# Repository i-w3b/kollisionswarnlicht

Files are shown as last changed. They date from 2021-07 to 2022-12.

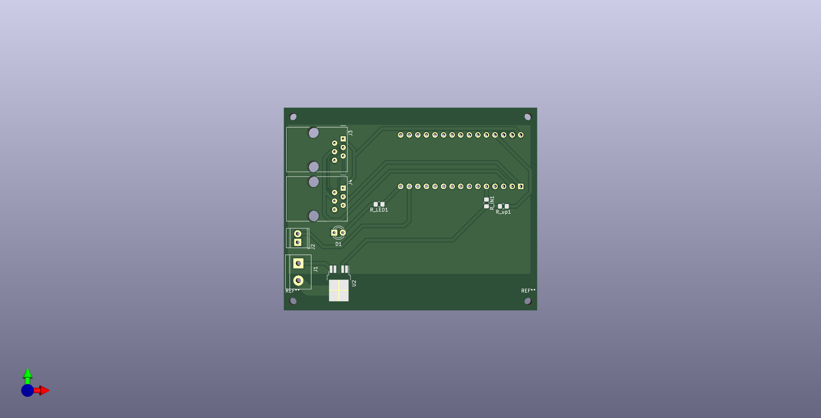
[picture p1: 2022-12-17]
Controller_extLED_noDiagnosis/3DView.png

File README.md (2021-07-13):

### kollisionswarnlicht

| Part | Datenblatt | Preis |
|:---:|:---:|:---:|
|[Controller(Atmega32U4AU)](https://www.digikey.de/product-detail/de/microchip-technology/ATMEGA32U4-AU/ATMEGA32U4-AU-ND/1914602)| [Datenblatt](https://ww1.microchip.com/downloads/en/DeviceDoc/Atmel-7766-8-bit-AVR-ATmega16U4-32U4_Datasheet.pdf)  | €3,81 |
| [USB-Anschluss](https://www.digikey.de/product-detail/de/gct/USB3075-30-A/2073-USB3075-30-ACT-ND/9859705)| - | €0,55 | 
| [RJ12-Anschluss](https://www.digikey.de/product-detail/de/pulse-electronics-network/E5566-Q0LK22-L/553-2258-ND/1785239) | - | €0,45 |
| [Quartz - Alt](https://www.digikey.de/product-detail/de/txc-corporation/7A-16.000MAAJ-T/887-1086-2-ND/2118770) | - | €0,31 |
| [Quartz](https://www.digikey.de/product-detail/de/epson/FA-238-16-0000MB-C3/SER3686CT-ND/2403459) | - | €0,27 |
| [LED](https://www.digikey.de/product-detail/de/cree-inc/XHP50A-00-0000-0D0BJ40E2/XHP50A-00-0000-0D0BJ40E2TR-ND/5303071) | [Datenblatt](https://cree-led.com/media/documents/ds-XHP50.pdf) | €4,53 |
| [LED-Treiber](https://www.digikey.de/product-detail/de/leddynamics-inc/3021-D-E-1000/788-1107-ND/3114438) | [Datenblatt](http://www.leddynamics.com/wp-content/uploads/2018/11/03021_03023_BuckPuck_v3-1.pdf)| €7,83 |
| [PNP-Transistor](https://www.digikey.de/product-detail/de/taiwan-semiconductor-corporation/MMBT3906-RFG/MMBT3906RFGCT-ND/7644317) | [Datenblatt](https://www.taiwansemi.com/assets/uploads/datasheet/MMBT3906_H2001.pdf) | €0,03 |
| [Load-Switch](https://www.digikey.de/product-detail/de/infineon-technologies/BTS71202EPAXUMA1/BTS71202EPAXUMA1CT-ND/9906589) | [Datenblatt](https://www.infineon.com/dgdl/Infineon-BTS7120-2EPA-DS-v01_00-EN.pdf?fileId=5546d462636cc8fb016421dc08d31138) | 1,41€ |
| [220uF Kondensator](https://www.digikey.de/products/de?keywords=P124108CT-ND) | [Datenblatt](https://industrial.panasonic.com/cdbs/www-data/pdf/RDD0000/RDD0000C1244.pdf) |2,61€ |
| [Poti](https://www.digikey.de/product-detail/de/nidec-copal-electronics/ST32ETA502/ST32ETA502CT-ND/738477) | [Datenblatt](https://www.nidec-copal-electronics.com/e/catalog/trimmer/st-32.pdf) | 1,09€ |

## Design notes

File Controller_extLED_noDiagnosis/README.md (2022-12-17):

## Blitzer

[Aveo Glider Burst NG Daylite](https://www.aveoengineering.com/downloads/GliderBurstNG.pdf)

## Infineon BTS High Side Smart Switches (PROFET)

Folgende Varianten diese Bauteils können haben einen identischen Footprint und können beispielsweise benutzt werden:

| Sensor | I_nominal | R_in | I_lim | Umin | Umax |
| --- | --- | --- | --- | --- | --- |
| [BTS462T](https://www.infineon.com/dgdl/Infineon-BTS462T-DS-v01_01-EN.pdf?fileId=5546d4625a888733015aa9b0294035f6)|  3.5 | 100 | 20 | 5 | 34 |
| [BTS441TG](https://www.infineon.com/dgdl/Infineon-BTS441TG-DS-v01_21-EN.pdf?fileId=5546d4625a888733015aa9afd69935dd) | 21 | 20 | 65 | 4.75 | 41 | 

Diese BTS sind bei Mouser verfügbar. 
Die Leistung wird geschaltet, wenn der Input auf Logical High liegt (Threshold 2.2 V)

## Mikrocontroller

Es wird ein Arduino Nano Board verwendet. Das Board gibt es in zwei Ausführungen, die beide benutzt werden können:

- [Arduino Nano A000005](https://docs.arduino.cc/static/68df964c1200093b9d91d4f424792425/A000005-datasheet.pdf) mit ATMega32U
- [Arduino Nano Every](https://docs.arduino.cc/static/824d5f3c9dcd3fd4339cac42032322dd/ABX00028-datasheet.pdf) mit ATMega4809 

## Sonstiges

### Status LED

Es ist eine 3mm rote Status-LED vorgesehen. Der Forward Current sollte den maximalen Strom der einzelnen Pins des Arduino nicht überschreiten. Empfohlen werden 10 mA für den Nano Every, zum Beispiel [Vishay TLHR4400](https://www.mouser.de/ProductDetail/Vishay-Semiconductors/TLHR4400-AS12Z?qs=nQ9vpdMXC6AwxmxsGskxgg%3D%3D).

### Zweiter RJ12 Stecker

Es sind zwei RJ12 Flarm Datenstecker verbaut, um das Signal an weitere Geräte zu geben, ohne einen Splitter zu verbauen.

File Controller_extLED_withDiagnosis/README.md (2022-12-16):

## Blitzer

[Aveo Glider Burst NG Daylite](https://www.aveoengineering.com/downloads/GliderBurstNG.pdf)

## Infineon BTS High Side Smart Switches (PROFET)

Folgende Varianten diese Bauteils können haben einen identischen Footprint und können beispielsweise benutzt werden:

| Sensor | I_nominal | R_in | I_lim | Umin | Umax |
| --- | --- | --- | --- | --- | --- |
|[BTS443P](https://www.infineon.com/dgdl/Infineon-BTS443P-DS-v01_00-EN.pdf?fileId=5546d4625a888733015aa9afbc5035d5)|  25 | 16 | 65 | 5 | 36 | 
|[BTS6143D](https://www.infineon.com/dgdl/Infineon-BTS6143D-DS-v01_00-EN.pdf?fileId=5546d4625a888733015aa3da10821022) | 8 | 10 | 75 | 5.5 | 38 | 
|[BTS6133D](https://www.infineon.com/dgdl/Infineon-BTS6133D-DS-v01_00-EN.pdf?fileId=5546d4625a888733015aa3e3286f102a)  | 8 | 10 | 75 | 5.5 | 38 | 
|[BTS5012SDA](https://www.infineon.com/dgdl/Infineon-BTS5012SDA-DS-v01_01-en.pdf?fileId=db3a30431d8a6b3c011db95c6eba237d)  | 6.5 | 25 | 65 | 5.5 | 38 | 

Diese BTS sind bei Mouser verfügbar. 
Die Leistung wird geschaltet, wenn der V_in auf GND liegt.

## Mikrocontroller

Es wird ein Arduino Nano Board verwendet. Das Board gibt es in zwei Ausführungen, die beide benutzt werden können:

- [Arduino Nano A000005](https://docs.arduino.cc/static/68df964c1200093b9d91d4f424792425/A000005-datasheet.pdf) mit ATMega32U
- [Arduino Nano Every](https://docs.arduino.cc/static/824d5f3c9dcd3fd4339cac42032322dd/ABX00028-datasheet.pdf) mit ATMega4809 

## Sonstiges

### Status LED

Es ist eine 3mm rote Status-LED vorgesehen. Der Forward Current sollte den maximalen Strom der einzelnen Pins des Arduino nicht überschreiten. Empfohlen werden 10 mA für den Nano Every, zum Beispiel [Vishay TLHR4400](https://www.mouser.de/ProductDetail/Vishay-Semiconductors/TLHR4400-AS12Z?qs=nQ9vpdMXC6AwxmxsGskxgg%3D%3D).

### Zweiter RJ12 Stecker

Es sind zwei RJ12 Flarm Datenstecker verbaut, um das Signal an weitere Geräte zu geben, ohne einen Splitter zu verbauen.

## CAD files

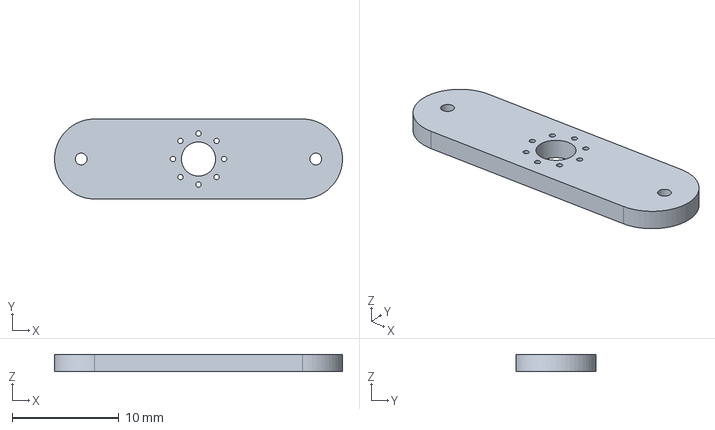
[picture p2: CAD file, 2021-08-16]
Controller_withLED/Haubenblitzer_Treiber/Haubenblitzer_Treiber.step
27.0 x 7.50 x 1.60 mm

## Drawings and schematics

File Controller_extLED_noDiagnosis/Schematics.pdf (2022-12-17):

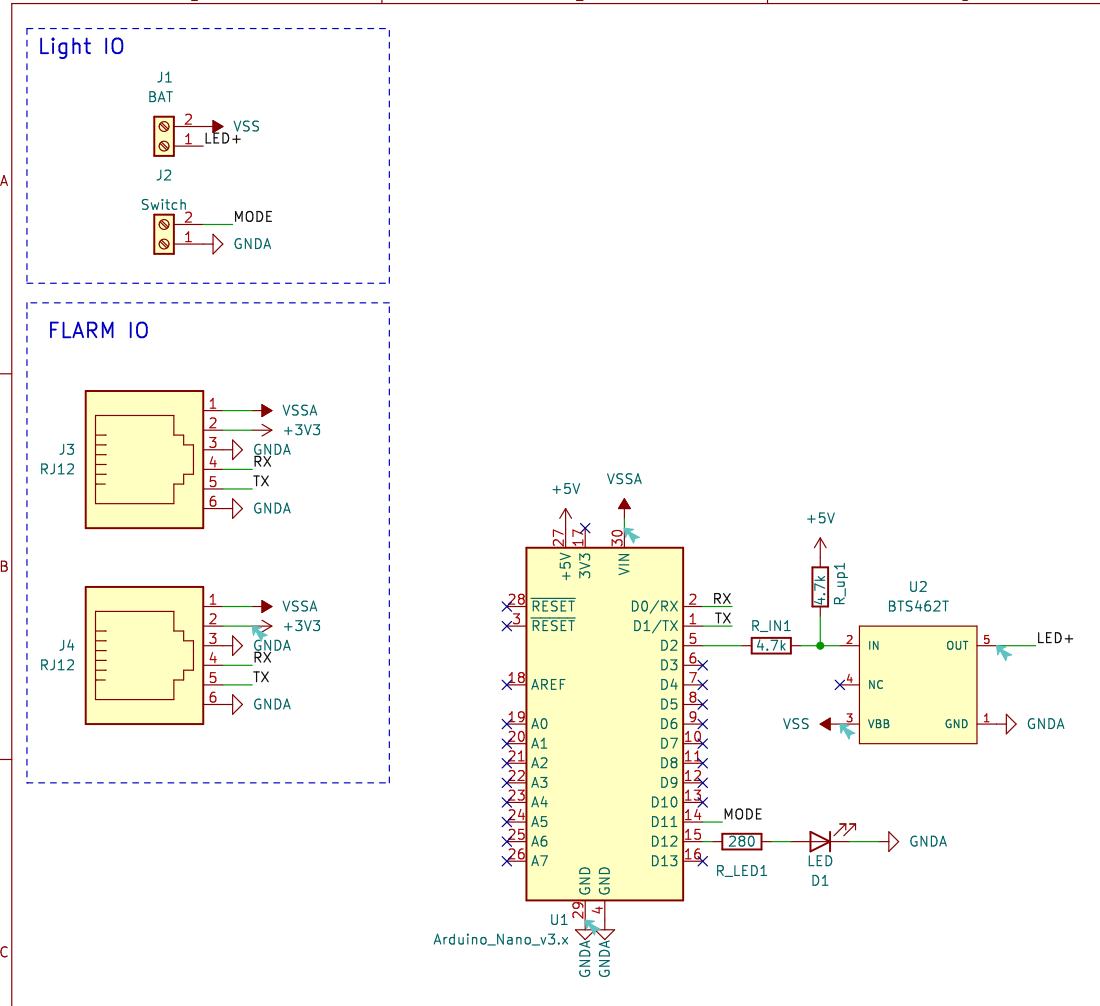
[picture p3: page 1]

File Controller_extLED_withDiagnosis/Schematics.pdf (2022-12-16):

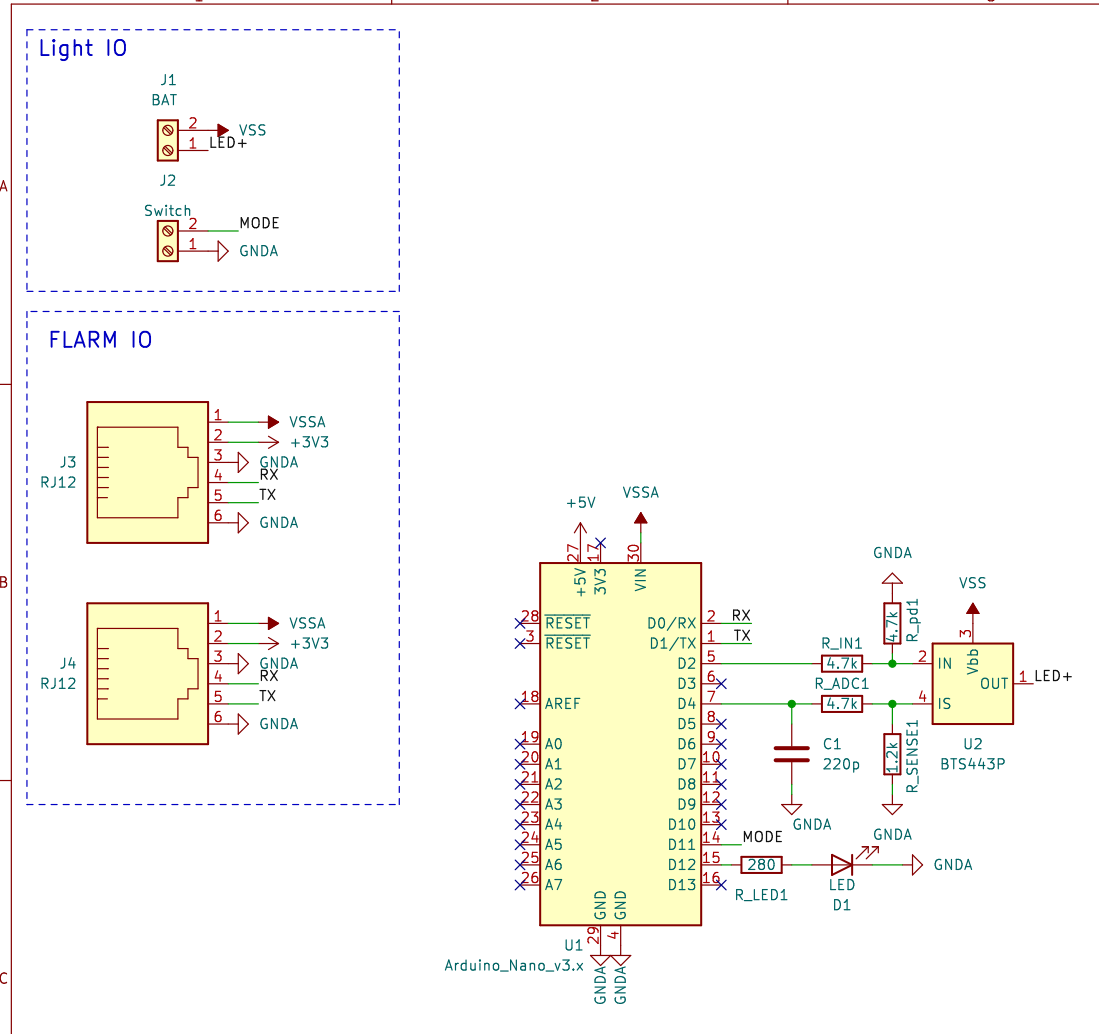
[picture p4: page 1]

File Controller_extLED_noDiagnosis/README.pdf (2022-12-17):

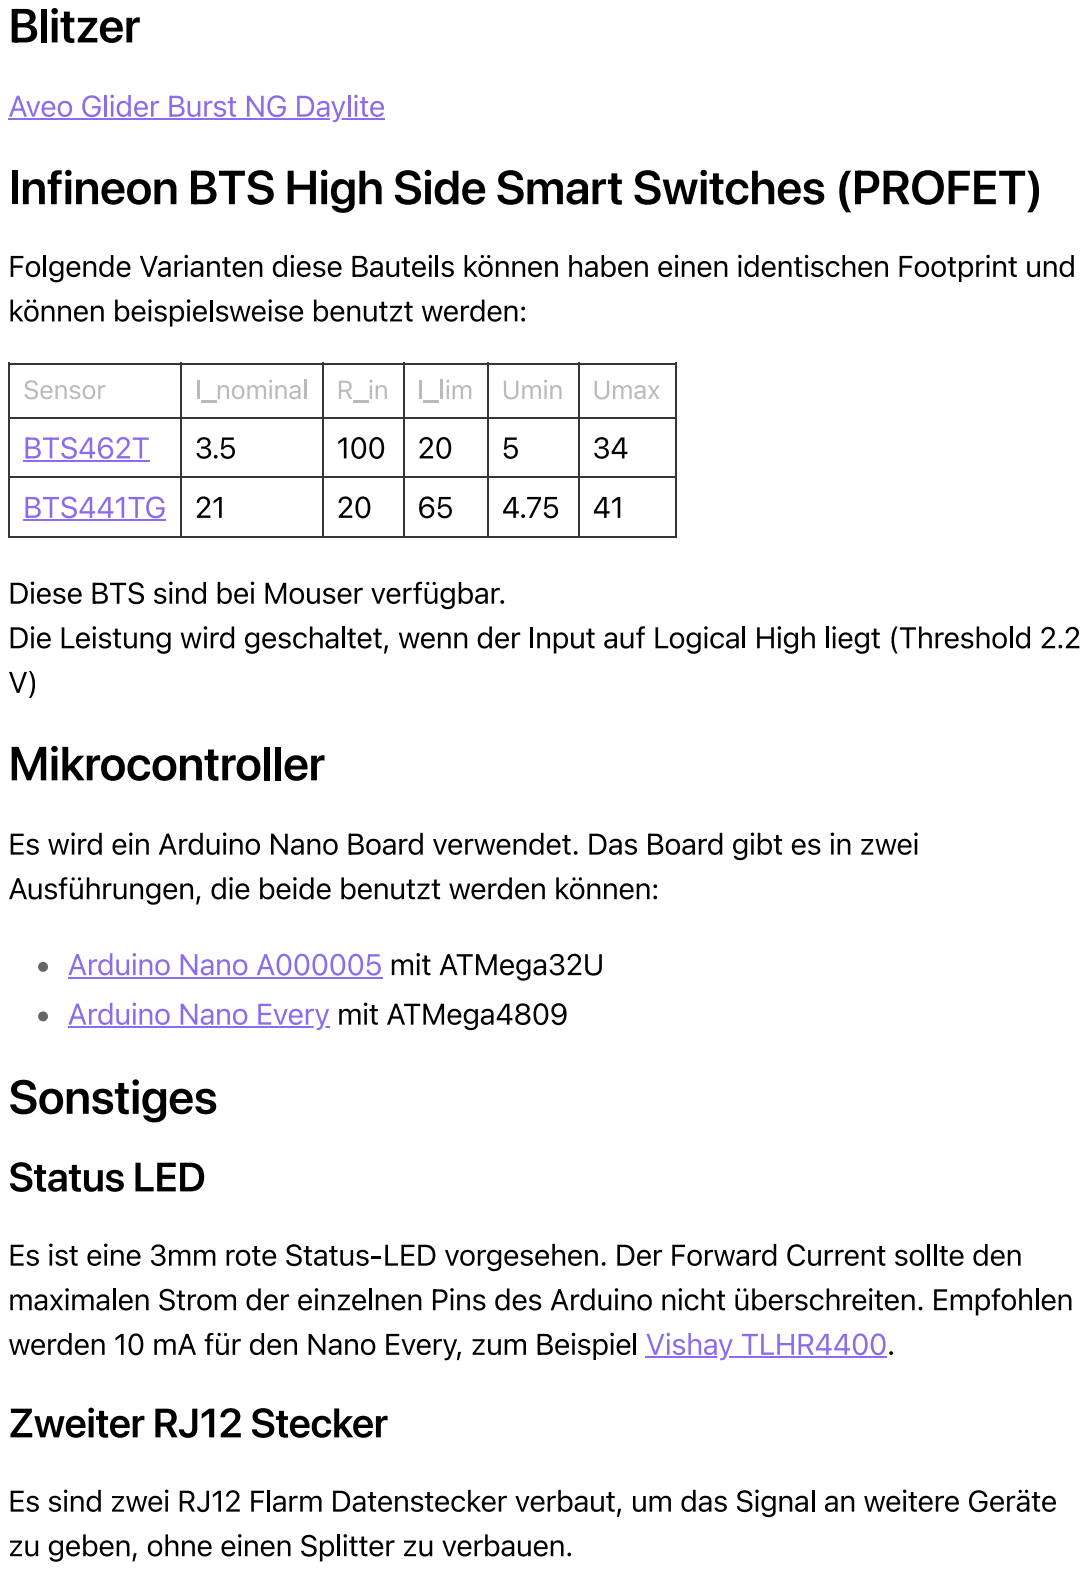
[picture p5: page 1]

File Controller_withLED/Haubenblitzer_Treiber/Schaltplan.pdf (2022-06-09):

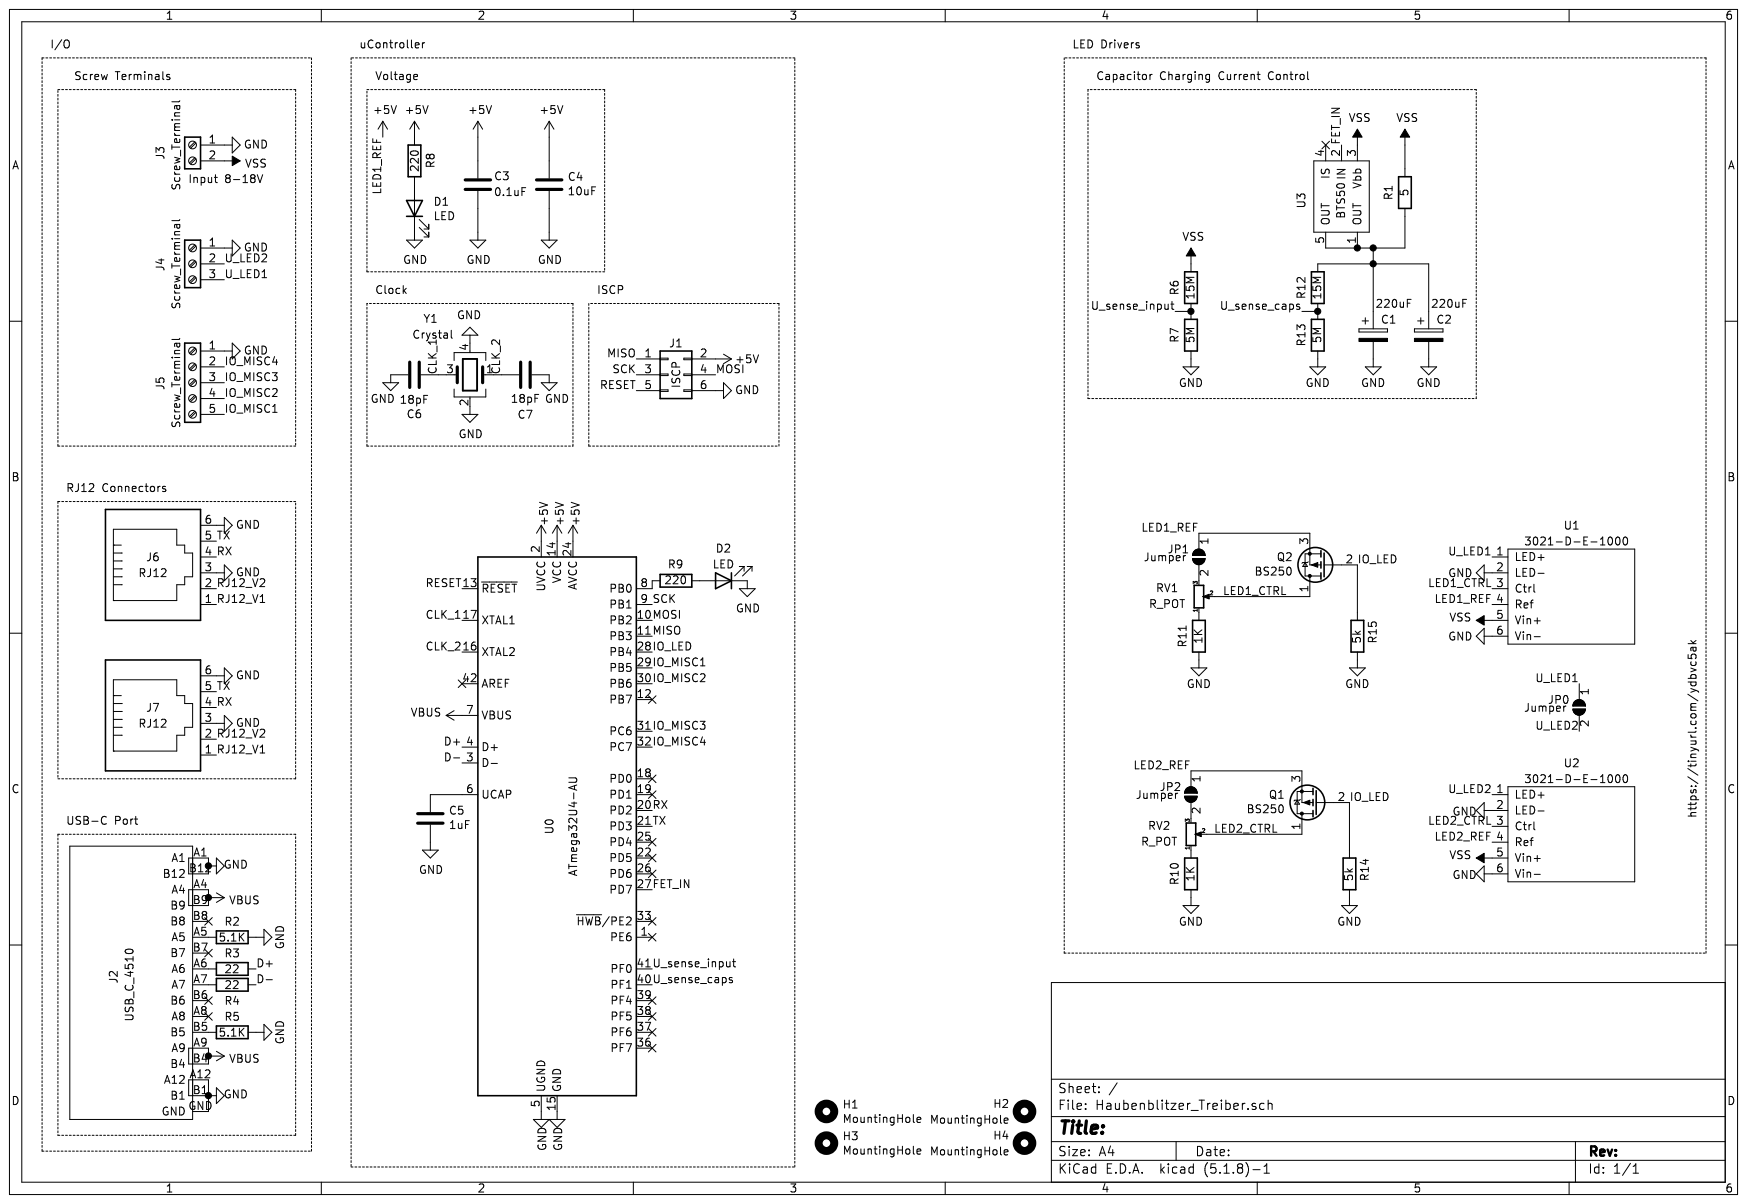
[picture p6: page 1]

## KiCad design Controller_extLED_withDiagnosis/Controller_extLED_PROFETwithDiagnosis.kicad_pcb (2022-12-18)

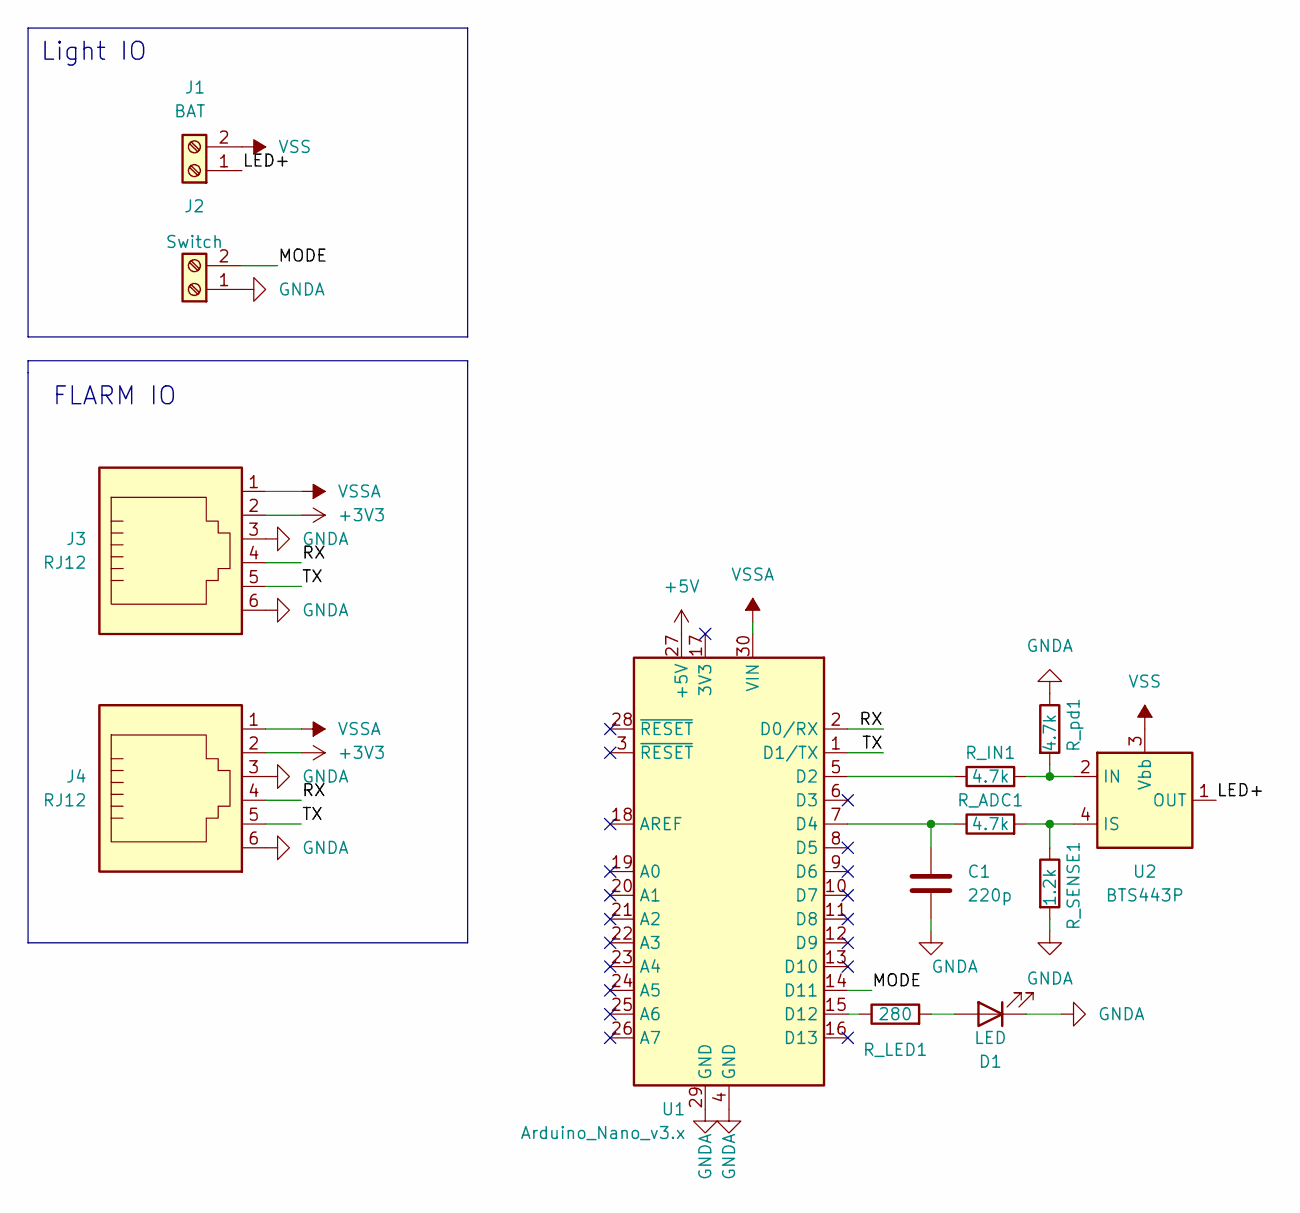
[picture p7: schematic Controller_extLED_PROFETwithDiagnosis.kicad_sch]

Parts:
C1: 220p; C_0805_2012Metric_Pad1.18x1.45mm_HandSolder
D1: LED; LED_D3.0mm
J1: BAT; TerminalBlock_bornier-2_P5.08mm
J2: Switch; TerminalBlock_TE_282834-2_1x02_P2.54mm_Horizontal
J3, J4: RJ12; RJ12_Amphenol_54601
R_ADC1: 4.7k; R_0805_2012Metric_Pad1.20x1.40mm_HandSolder
R_IN1: 4.7k; R_0805_2012Metric_Pad1.20x1.40mm_HandSolder
R_LED1: 280; R_0805_2012Metric_Pad1.20x1.40mm_HandSolder
R_SENSE1: 1.2k; R_0805_2012Metric_Pad1.20x1.40mm_HandSolder
R_pd1: 4.7k; R_0805_2012Metric_Pad1.20x1.40mm_HandSolder
U1: Arduino_Nano_v3.x; Arduino_Nano
U2: BTS443P; TO-252-4

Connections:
+3V3: J3.2, J4.2
+5V: U1.27 (+5V)
/LED+: J1.1, U2.1 (OUT), U2.5 (OUT)
/MODE: J2.2, U1.14 (D11)
/RX: J3.4, J4.4, U1.2 (D0/RX)
/TX: J3.5, J4.5, U1.1 (D1/TX)
GNDA: C1.2, D1.1 (K), J2.1, J3.3, J3.6, J4.3, J4.6, R_SENSE1.2, R_pd1.1, U1.4 (GND), U1.29 (GND)
unnamed: C1.1, R_ADC1.1, U1.7 (D4)
unnamed: D1.2 (A), R_LED1.2
unnamed: R_ADC1.2, R_SENSE1.1, U2.4 (IS)
unnamed: R_IN1.2, R_pd1.2, U2.2 (IN)
unnamed: R_LED1.1, U1.15 (D12)
unnamed: R_IN1.1, U1.5 (D2)
VSS: J1.2, U2.3 (Vbb)
VSSA: J3.1, J4.1, U1.30 (VIN)

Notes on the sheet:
Light IO
FLARM IO

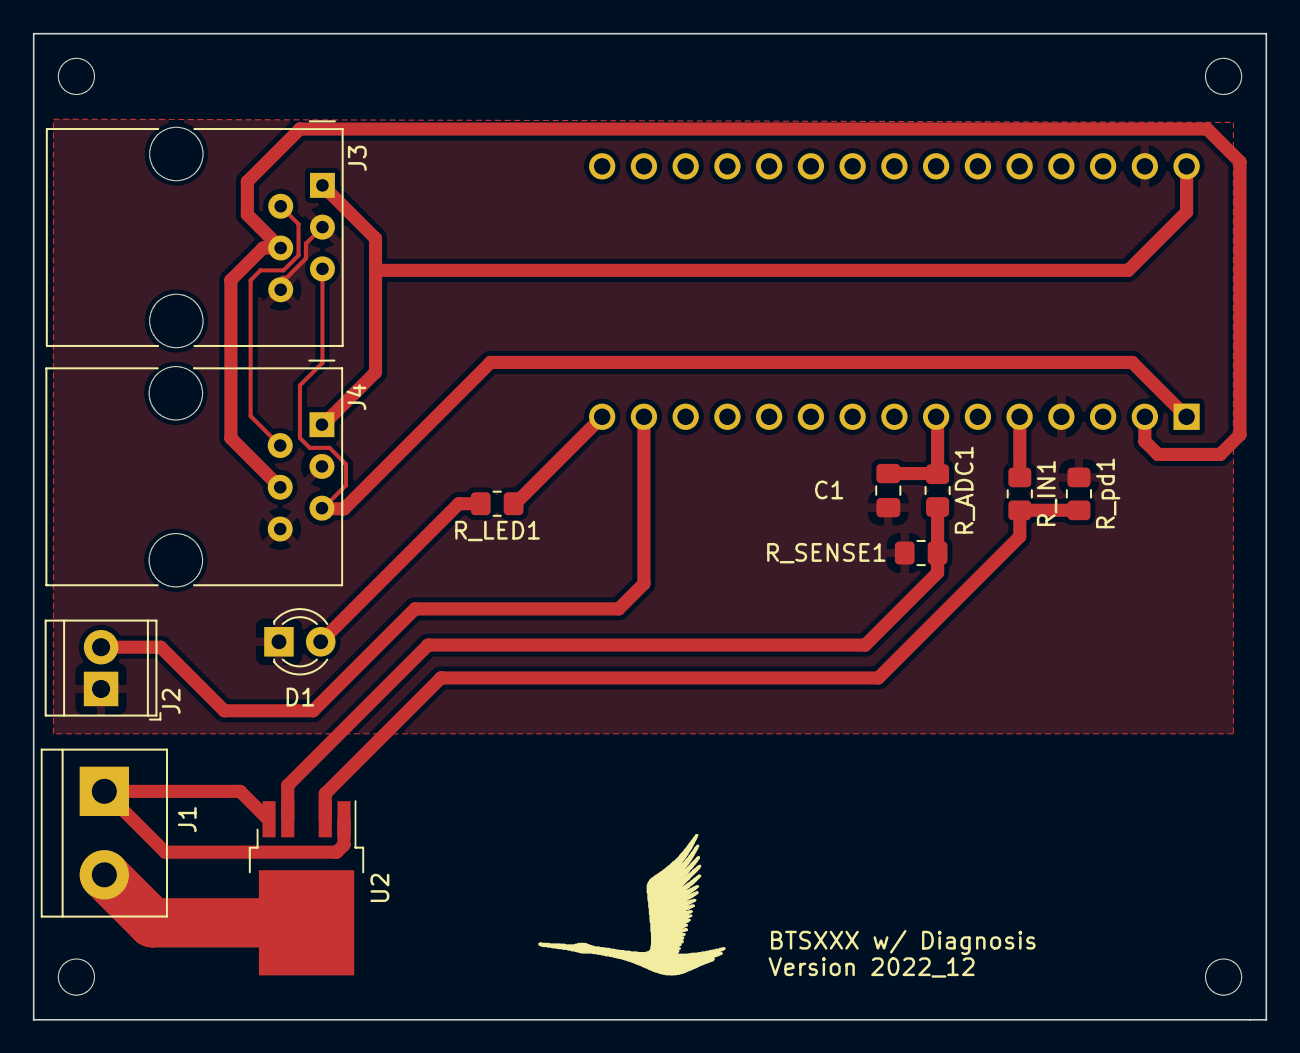
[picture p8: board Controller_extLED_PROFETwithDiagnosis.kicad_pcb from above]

Board: 2 copper layers, 75.0 x 60.0 mm, 13 parts (1 on the bottom side), 14 nets.

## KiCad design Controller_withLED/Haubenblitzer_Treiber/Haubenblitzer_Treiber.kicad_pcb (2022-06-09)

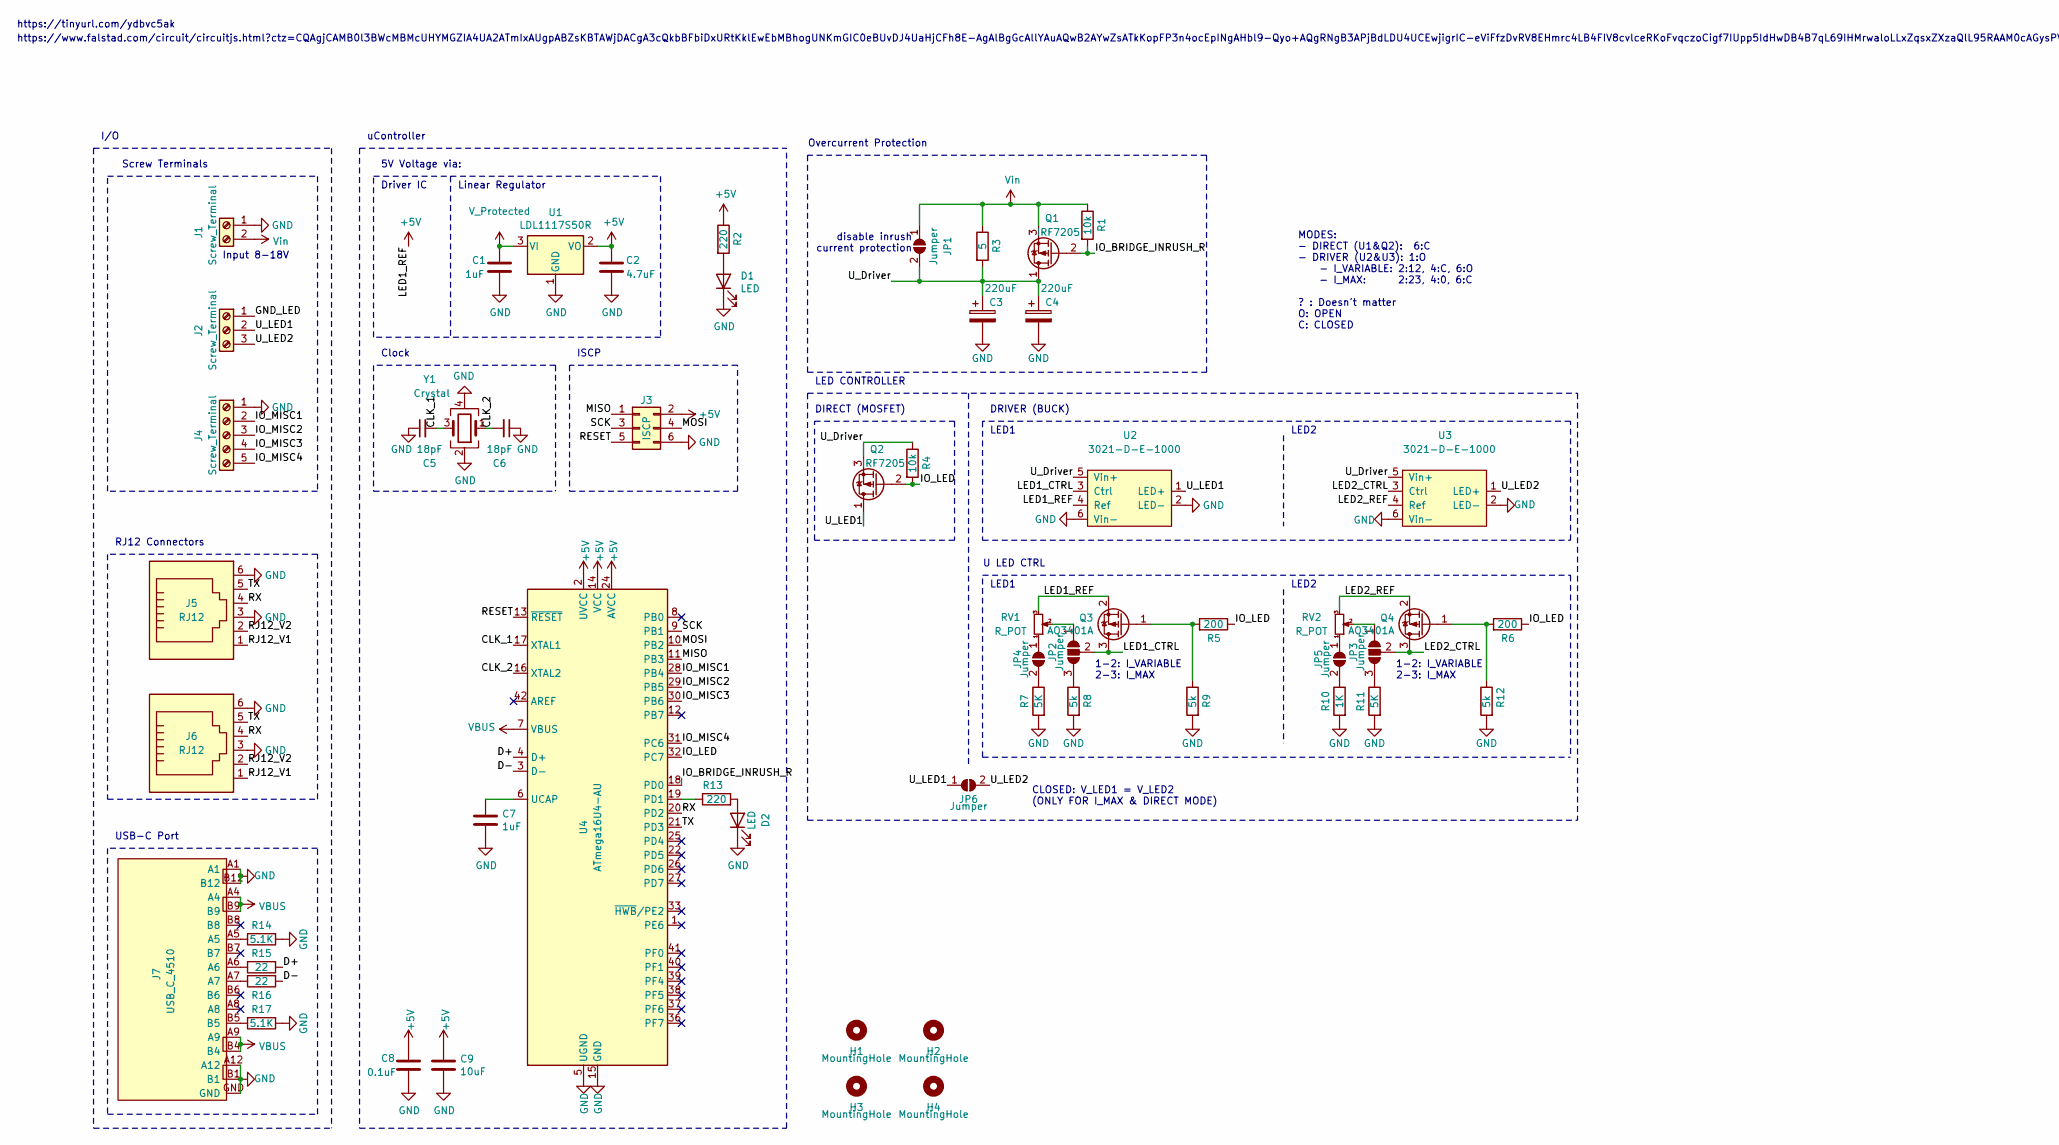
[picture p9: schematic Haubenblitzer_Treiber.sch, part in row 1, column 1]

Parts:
C1, C7: 1uF; C_0805_2012Metric
C2: 4.7uF; C_0805_2012Metric
C3, C4: 220uF; CP_Elec_10x10
C5, C6: 18pF; C_0805_2012Metric
C8: 0.1uF; C_0805_2012Metric
C9: 10uF; C_0805_2012Metric
D1, D2: LED; LED_0805_2012Metric
H1, H2, H3, H4: MountingHole; MountingHole_3.2mm_M3
J1: Screw_Terminal; TerminalBlock_4Ucon_1x02_P3.50mm_Horizontal
J2: Screw_Terminal; TerminalBlock_4Ucon_1x03_P3.50mm_Horizontal
J3: ISCP; PinHeader_2x03_P2.54mm_Vertical
J4: Screw_Terminal; TerminalBlock_4Ucon_1x05_P3.50mm_Horizontal
J5, J6: RJ12; RJ25_Wayconn_MJEA-660X1_Horizontal
J7: USB_C_4510
JP1, JP6: Jumper; SolderJumper-2_P1.3mm_Open_Pad2.0x4.0mm
JP2, JP3: Jumper; SolderJumper-3_P1.3mm_Open_RoundedPad1.0x1.5mm
JP4, JP5: Jumper; SolderJumper-2_P1.3mm_Open_RoundedPad1.0x1.5mm
Q1, Q2: IRF7205; SOIC-8_IRF7205
Q3, Q4: AO3401A; SOT-23
R1, R4: 10k; R_0805_2012Metric
R2, R13: 220; R_0805_2012Metric
R3: 5; PAK-2
R5, R6: 200; R_0805_2012Metric
R7, R11: 5K; R_0805_2012Metric
R8, R9, R12: 5k; R_0805_2012Metric
R10: 1K; R_0805_2012Metric
R14, R17: 5.1K; R_0805_2012Metric
R15, R16: 22; R_0805_2012Metric
RV1, RV2: R_POT; Potentiometer_ACP_PS10_Vertical_Hole
U1: LDL1117S50R; SOT-223
U2, U3: 3021-D-E-1000
U4: ATmega16U4-AU; QFN-44-1EP_7x7mm_P0.5mm_EP5.2x5.2mm
Y1: Crystal; Crystal_SMD_3225-4Pin_3.2x2.5mm

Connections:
+5V: C2.2, C8.2, C9.2, J3.2, Q3.2 (S), R2.1, RV1.3, U1.2 (VO), U2.4 (Ref), U4.2 (UVCC), U4.14 (VCC), U4.24 (AVCC), U4.34 (VCC), U4.44 (AVCC)
/CLK_1: C5.2, U4.17 (XTAL1), Y1.3
/CLK_2: C6.2, U4.16 (XTAL2), Y1.1
/D+: R15.2, U4.4 (D+)
/D-: R16.2, U4.3 (D-)
/GND_LED: J2.1
/IO_BRIDGE_INRUSH_R: Q1.2 (G), R1.2, U4.18 (PD0)
/IO_LED: Q2.2 (G), R4.2, R5.1, R6.1, U4.32 (PC7)
/IO_MISC1: J4.2, U4.28 (PB4)
/IO_MISC2: J4.3, U4.29 (PB5)
/IO_MISC3: J4.4, U4.30 (PB6)
/IO_MISC4: J4.5, U4.31 (PC6)
/LED1_CTRL: JP2.2 (C), Q3.3 (D), U2.3 (Ctrl)
/LED2_CTRL: JP3.2 (C), Q4.3 (D), U3.3 (Ctrl)
/LED2_REF: Q4.2 (S), RV2.3, U3.4 (Ref)
/MISO: J3.1, U4.11 (PB3)
/MOSI: J3.4, U4.10 (PB2)
/RESET: J3.5, U4.13 (~RESET)
/RJ12_V1: J5.1, J6.1
/RJ12_V2: J5.2, J6.2
/RX: J5.4, J6.4, U4.20 (PD2)
/SCK: J3.3, U4.9 (PB1)
/TX: J5.5, J6.5, U4.21 (PD3)
/U_Driver: C3.1, C4.1, JP1.2 (B), Q1.1 (D), Q2.3 (S), R3.2, R4.1, U2.5 (Vin+), U3.5 (Vin+)
/U_LED1: J2.2, JP6.1 (A), Q2.1 (D), U2.1 (LED+)
/U_LED2: J2.3, JP6.2 (B), U3.1 (LED+)
GND: C1.1, C2.1, C3.2, C4.2, C5.1, C6.1, C7.1, C8.1, C9.1, D1.1 (K), D2.1 (K), J1.1, J3.6, J4.1, J5.3, J5.6, J6.3, J6.6, J7.A1, J7.A12, J7.B1, J7.B12, J7.GND, R7.2, R8.2, R9.2, R10.2, R11.2, R12.2, R14.2, R17.2, U1.1 (GND), U2.2 (LED-), U2.6 (Vin-), U3.2 (LED-), U3.6 (Vin-), U4.5 (UGND), U4.15 (GND), U4.23 (GND), U4.35 (GND), U4.43 (GND), Y1.2, Y1.4; also elsewhere on the board
unnamed: C7.2, U4.6 (UCAP)
unnamed 28: D1.2 (A), R2.2; also elsewhere on the board
unnamed 29: D2.2 (A), R13.2; also elsewhere on the board
unnamed: J7.A5, R14.1
unnamed: J7.A6, R15.1
unnamed: J7.A7, R16.1
unnamed: J7.B5, R17.1
unnamed: JP2.1 (A), RV1.2
unnamed: JP2.3 (B), R8.1
unnamed: JP3.1 (A), RV2.2
unnamed: JP3.3 (B), R11.1
unnamed: JP4.1 (A), RV1.1
unnamed: JP4.2 (B), R7.1
unnamed: JP5.1 (A), RV2.1
unnamed: JP5.2 (B), R10.1
unnamed: Q3.1 (G), R5.2, R9.1
unnamed: Q4.1 (G), R6.2, R12.1
unnamed: R13.1, U4.19 (PD1)
VBUS: J7.A4, J7.A9, J7.B4, J7.B9, U4.7 (VBUS)

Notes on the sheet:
https://www.falstad.com/circuit/circuitjs.html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…
Input 8-18V
5V Voltage via:
https://tinyurl.com/ydbvc5ak
I/O
uController
Clock
ISCP
USB-C Port
RJ12 Connectors
Screw Terminals
CLOSED: V_LED1 = V_LED2 (ONLY FOR I_MAX & DIRECT MODE)
U LED CTRL
DRIVER (BUCK)
1-2: I_VARIABLE 2-3: I_MAX
DIRECT (MOSFET)
Overcurrent Protection
LED CONTROLLER
LED1
LED2
MODES: - DIRECT (U1&Q2): 6:C - DRIVER (U2&U3): 1:O - I_VARIABLE: 2:12, 4:C, 6:O - I_MAX: 2:23, 4:0, 6:C ? : Doesn't matter O: OPEN C: CLOSED
Driver IC
Linear Regulator
disable inrush current protection

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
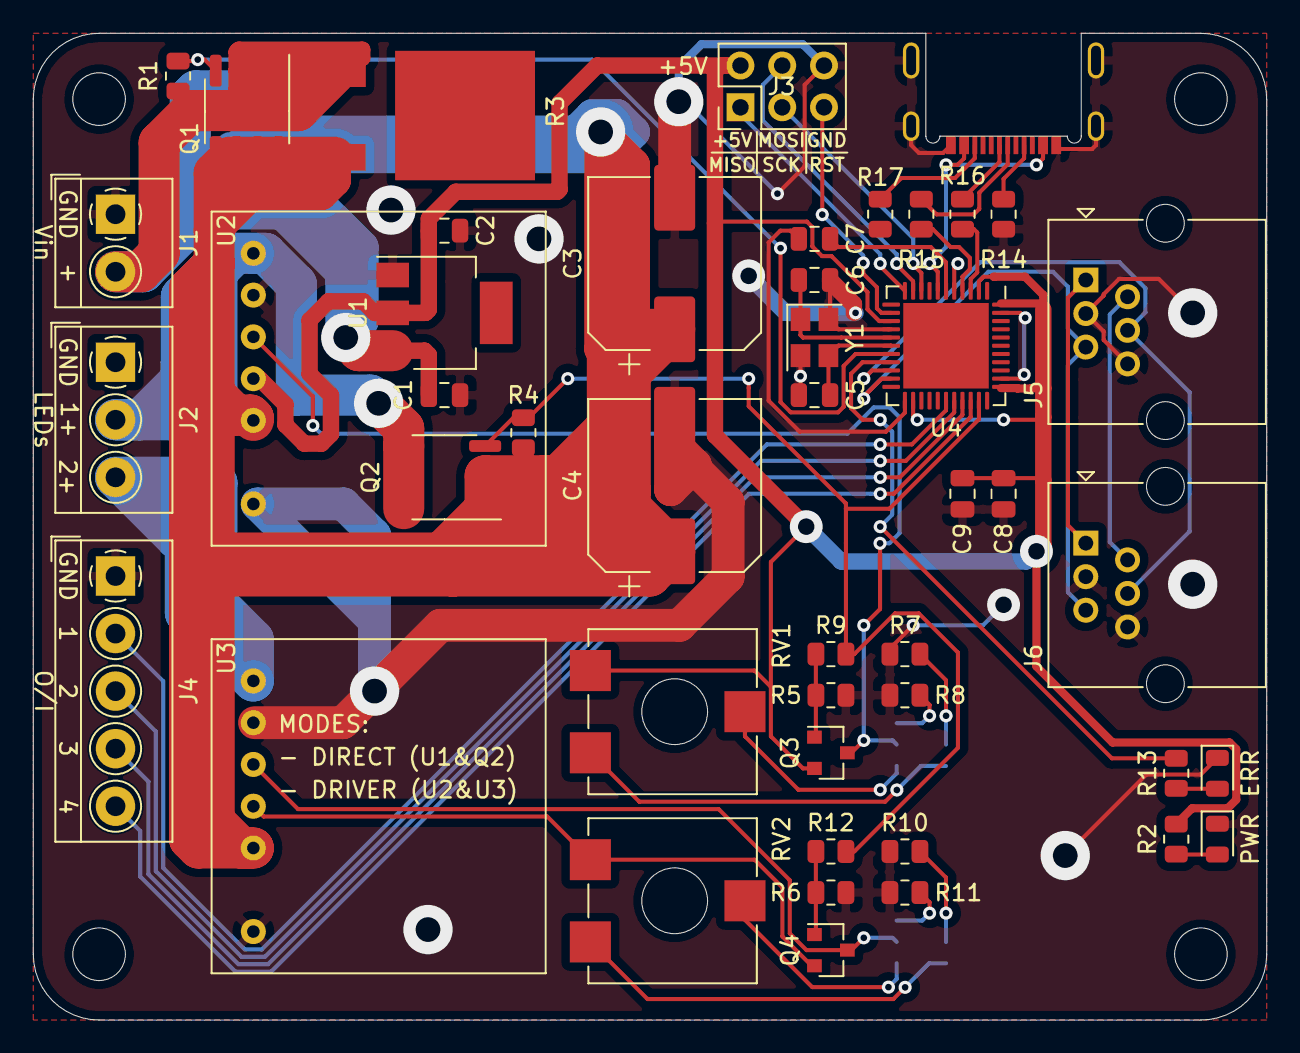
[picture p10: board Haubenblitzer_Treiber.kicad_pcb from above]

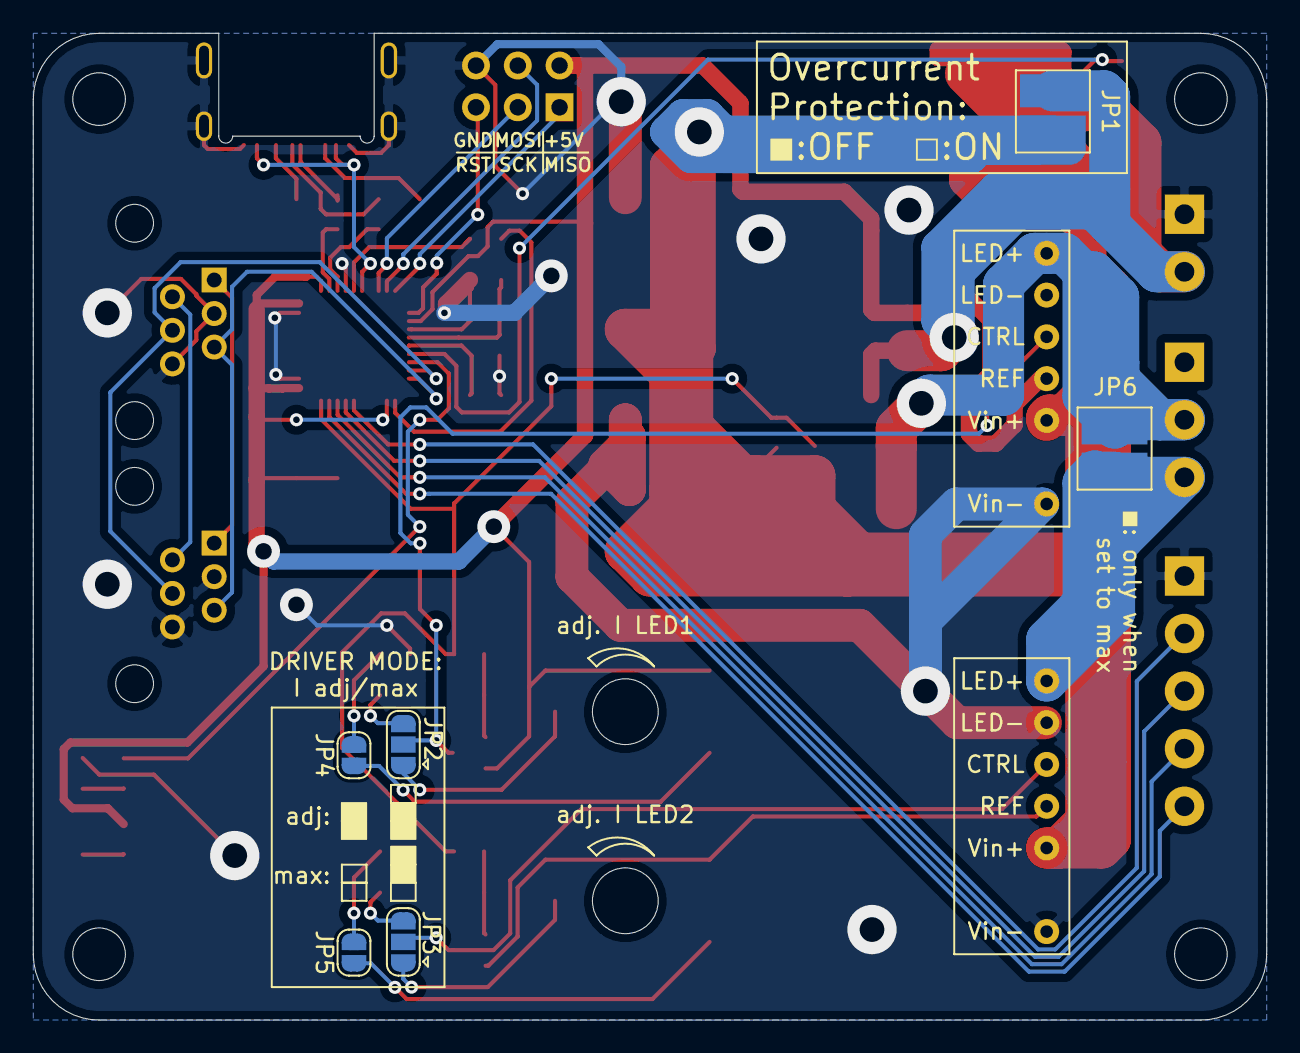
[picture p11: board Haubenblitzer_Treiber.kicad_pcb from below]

Board: 2 copper layers, 75.0 x 60.0 mm, 56 parts (6 on the bottom side), 46 nets.

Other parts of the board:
ERR: LED; LED_0805_2012Metric
PWR: LED; LED_0805_2012Metric

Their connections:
GND: ERR.1, PWR.1; also elsewhere on the board
unnamed 28: PWR.2; also elsewhere on the board
unnamed 29: ERR.2; also elsewhere on the board

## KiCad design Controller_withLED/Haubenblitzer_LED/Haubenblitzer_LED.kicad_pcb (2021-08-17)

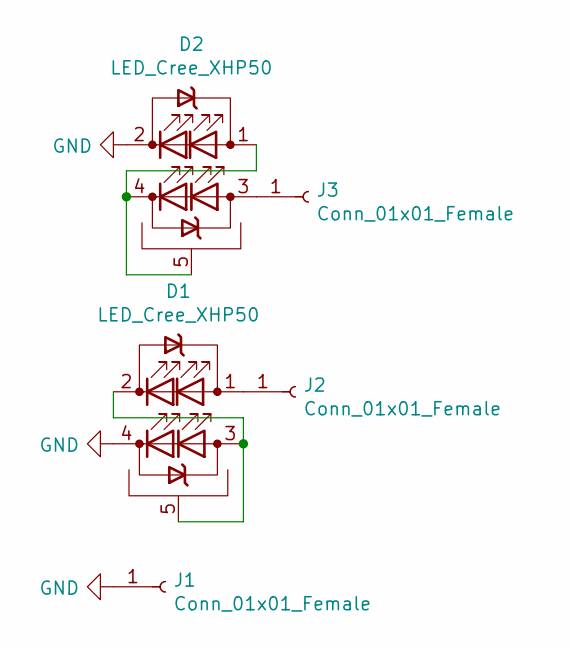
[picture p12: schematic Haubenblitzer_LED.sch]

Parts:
D1, D2: LED_Cree_XHP50; LED_Cree-XHP50
J1: Conn_01x01_Female; SolderWire-0.5sqmm_1x01_D0.9mm_OD2.3mm
J2, J3: Conn_01x01_Female; SolderWirePad_1x01_SMD_2.5x5mm

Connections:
GND: D1.4 (K), D2.2 (K), J1.1
unnamed: D1.1 (A), J2.1
unnamed: D1.2 (K), D1.3 (A), D1.5 (PAD)
unnamed: D2.1 (A), D2.4 (K), D2.5 (PAD)
unnamed: D2.3 (A), J3.1

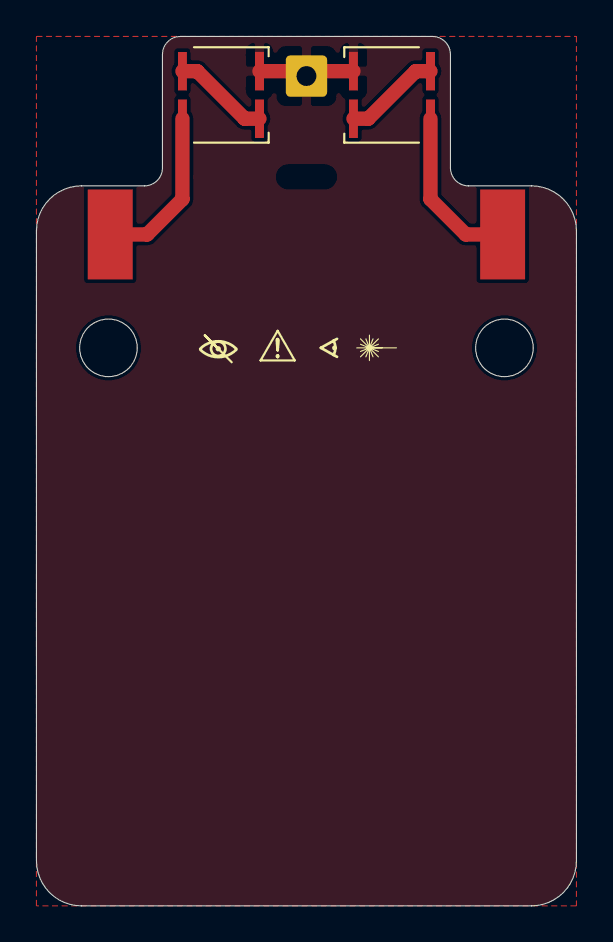
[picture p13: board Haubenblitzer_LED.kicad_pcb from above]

Board: 2 copper layers, 30.0 x 48.3 mm, 5 parts (0 on the bottom side), 5 nets.

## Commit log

2021-07-13 updated transistor, added Load-Switch, Poti
2021-08-17 added ESD protection and gerber files
    [Haubenblitzer_LED-Edge_Cuts.gbr, Haubenblitzer_LED-F_Adhes.gbr, Haubenblitzer_LED-F_Cu.gbr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]
2021-08-17 added ESD protection to USB port and gerber files
    [Haubenblitzer_Treiber-B_Adhes.gbr, Haubenblitzer_Treiber-B_Cu.gbr, Haubenblitzer_Treiber-B_Mask.gbr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]
2021-08-17 cleanup + added gerber files
    [Haubenblitzer_LED-Edge_Cuts.gbr, Haubenblitzer_LED-F_Adhes.gbr, Haubenblitzer_LED-F_Cu.gbr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]
2021-08-17 updated LED footprint
    [Haubenblitzer_LED-Edge_Cuts.gbr, Haubenblitzer_LED-F_Adhes.gbr, Haubenblitzer_LED-F_Cu.gbr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]
2022-12-16 version 0
    [Haubenblitzer_v2.kicad_pcb, Haubenblitzer_v2.kicad_sch]
2022-12-17 comprehensive renaming
    [Controller_extLED_PROFETwithDiagnosis.kicad_pcb, Controller_extLED_PROFETwithDiagnosis.kicad_sch]
2022-12-17 Controller for old Profet versions added
    [Controller_extLED_PROFETnoDiagnosis.kicad_pcb, Controller_extLED_PROFETnoDiagnosis.kicad_sch]
2022-12-17 renaming Jens design
    [Haubenblitzer_LED-Edge_Cuts.gbr, Haubenblitzer_LED-F_Adhes.gbr, Haubenblitzer_LED-F_Cu.gbr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]
2022-12-17 shorter naming
    [Controller_extLED_PROFETnoDiagnosis.kicad_pcb, Controller_extLED_PROFETnoDiagnosis.kicad_sch, Controller_extLED_PROFETwithDiagnosis.kicad_pcb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]
2022-12-17 moved J2 on Silkscreen
    [Controller_extLED_PROFETnoDiagnosis.kicad_pcb, Controller_extLED_PROFETwithDiagnosis.kicad_pcb]
2022-12-17 meved pull-up
    [Controller_extLED_PROFETnoDiagnosis.kicad_pcb]
2022-12-17 larger groundplane
    [Controller_extLED_PROFETnoDiagnosis.kicad_pcb]
2022-12-18 updated logo and silkscreen
    [Controller_extLED_PROFETwithDiagnosis.kicad_pcb]
2022-12-18 DRC weirness
    [Controller_extLED_PROFETwithDiagnosis.kicad_pcb]
